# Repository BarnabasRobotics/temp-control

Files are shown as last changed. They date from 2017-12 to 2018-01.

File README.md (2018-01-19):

# temp-control
Arduino-based temperature display and controller -- Created by Ling Leng

Revision History:
12/27/2017
- Added first version "Bare Bones Arduino.zip"
- Replaced "Bare Bones Arduino.zip" with new "TempControl V1.0" files which only includes .brd and .sch files
- Added Mini USB power supply part
- Added external oscillator
- Removed ISP-6 header
- Added reset button
- Added voltage regulator circuit

1/1/2018
- Added OLED
- Added .lbr file

1/2/2018
- Created new TempControl.lbr
- Created parts list
- Went through every parts and replaced them with TempControl.lbr
- Replaced ams1117 with L7805C
- Replaced the reset button
- Removed two LEDs
- Changed packages fot some capacitors
- Added frame

1/3/2018
- For U2, Added 0.33uF on Pin1 and 0.1uF on Pin3
- For U1, Added 0.1uF on Pin7 and 1.0uF on Pin20
- Added Diode on Pin1 for J3, Power Pin for J1, and VCC Pin for J4
- Added Green LED as power indicator
- Added a 4-PIN connector for OLED
- Rearranged and Rerouted the whole board

1/8/2018
- Removed power jack
- Removed 5V regulator
- Added 3v regulator
- Added level shifter

1/19/2018
- Added temp sensor

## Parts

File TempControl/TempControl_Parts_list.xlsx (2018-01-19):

Parts Name | Website | Price | Quantity | Comment | Custom Package
LD1117V33 | https://www.sparkfun.com/products/526 | 1.95 | 1
Micro USB | https://www.digikey.com/products/en?keywords=609-4618-1-ND | 0.46 | 1
ATMega328P | https://www.sparkfun.com/products/9061 | 4.3 | 1
FSM2JART(switch) | https://www.mouser.com/ProductDetail/TE-Connectivity/FSM2JART/ | 0.15 | 1 |  | 1
Logic Level Converter | https://www.sparkfun.com/products/12009 | 2.95 | 1
6-PIN |  |  | 1
8-PIN |  |  | 1
4-PIN |  |  | 1
LED RED DIFF 5MM ROUND T/H | https://www.digikey.com/product-detail/en/lite-on-inc/LTL-4223/160-1127-ND/200395 | 0.36 | 1
LED GREEN | https://www.digikey.com/products/en?keywords=160-1435-1-ND | 0.27 | 1
OLED | https://www.amazon.com/0-91-128x32-OLED-module-White/dp/B01IBCZB0M | 13.5 | 1 |  | 1
Crystal 16MHz | https://www.sparkfun.com/products/536 | 0.95 | 1
Schottky Diode | https://www.digikey.com/products/en?keywords=478-7802-1-ND | 0.54 | 2
Capacitor Ceramic Disc 22pF | http://www.sparkfun.com/products/8571 | 0.25 | 2
Capacitor Ceramic Disc 0.1uF | https://www.sparkfun.com/products/8375 | 0.25 | 3
Ceramic Capacitor 10uF | https://www.digikey.com/product-detail/en/tdk-corporation/FK24X5R1A106K/445-8493-ND/2815423 | 0.45 | 1
Ceramic Capacitor 1.0uF | https://www.digikey.com/product-detail/en/tdk-corporation/FK24X7R1H105K/445-8517-ND/2815447 | 0.4 | 1
Resistor 10K Ohm | https://www.sparkfun.com/products/14491 | 0.95 | 1
Resistor 4.7K Ohm | https://www.digikey.com/product-detail/en/stackpole-electronics-inc/CF14JT4K70/CF14JT4K70TR-ND/1741428 |  | 1
Resistor 1K Ohm | https://www.digikey.com/products/en?keywords=311-1.00KHRCT-ND | 0.1 | 2
Temperature Sensor - DS18B20 | https://www.sparkfun.com/products/245 | 3.95 | 1

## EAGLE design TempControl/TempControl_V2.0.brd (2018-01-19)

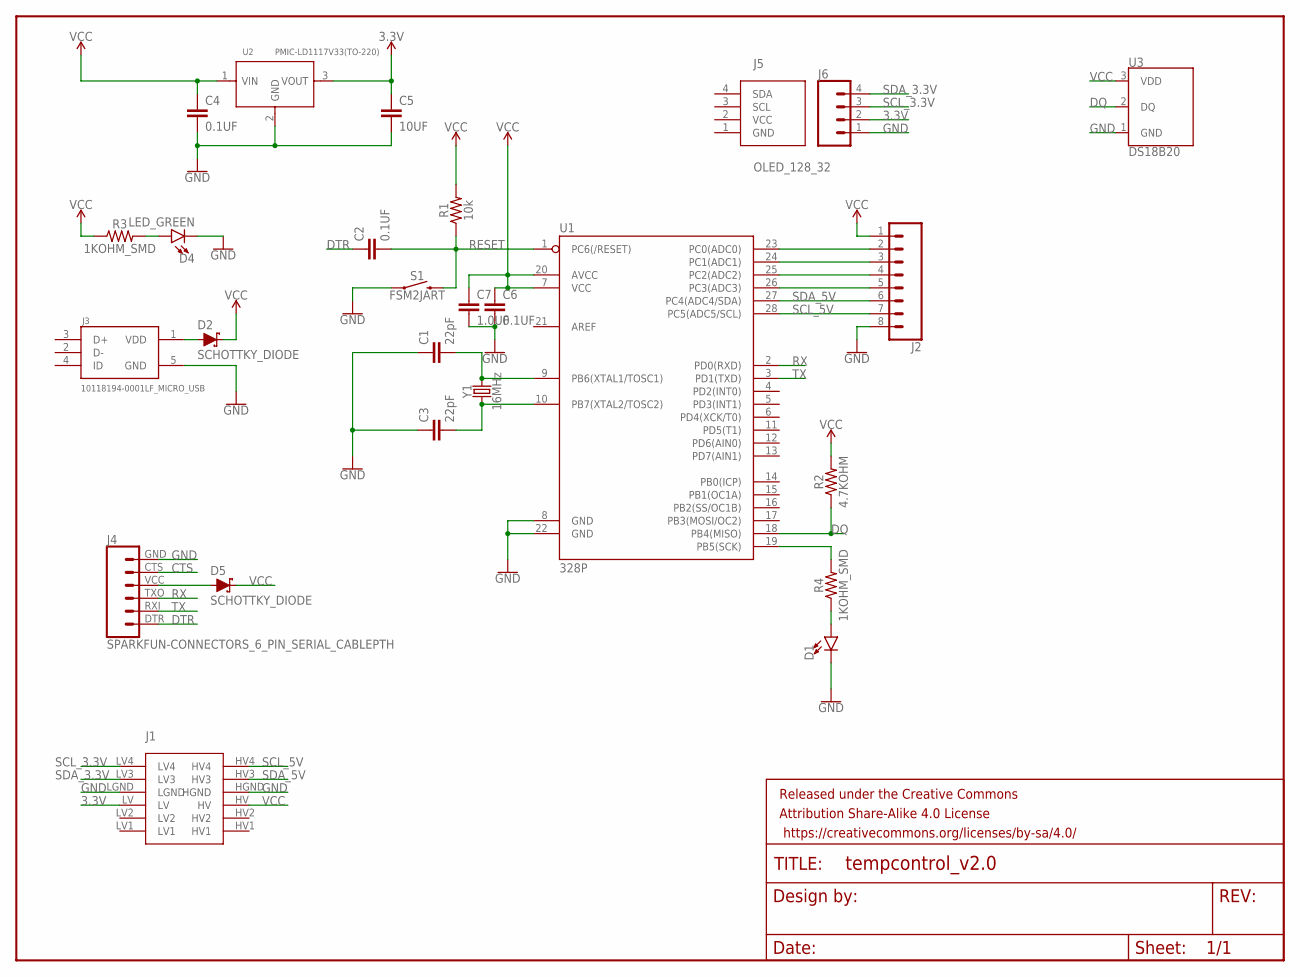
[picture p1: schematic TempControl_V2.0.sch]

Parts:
C1, C3: 22pF; CAP-PTH-2.54
C2, C4, C6: 0.1UF; CAP-PTH-2.54
C5: 10UF; CAP-PTH-5MM
C7: 1.0UF; CAP-PTH-5MM
D1: LED_RED5MM; LED_5MM
D2, D5: SCHOTTKY_DIODE; DIODE_0805
D4: LED_GREEN; LED-0603
FRAME1: FRAME-LETTERNO_PACKAGE; DUMMY
J1: LEVEL_SHIFTER
J2: SPARKFUN-CONNECTORS_CONN_08"; SPARKFUN-CONNECTORS_1X08
J3: 10118194-0001LF_MICRO_USB; FRAMATOME_10118194-0001LF
J4: SPARKFUN-CONNECTORS_6_PIN_SERIAL_CABLEPTH; SPARKFUN-CONNECTORS_FTDI_BASIC
J5: OLED_128_32
J6: CONN_04; 1X04
R1: 10k; AXIAL-0.3
R2: 4.7KOHM; AXIAL-0.3
R3, R4: 1KOHM_SMD; 0603
S1: FSM2JART
U1: 328P; DIP28
U2: PMIC-LD1117V33(TO-220); TO-220
U3: DS18B20; TO-92-AMMO
Y1: 16MHz; HC49US

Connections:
3.3V: C5.1, J1.LV, J6.2, U2.3 (VOUT)
CTS: J4.CTS (5)
DQ: R2.P$1 (1), U1.18 (PB4(MISO)), U3.2 (DQ)
DTR: C2.1, J4.DTR (1)
GND: C1.1, C3.1, C4.2, C5.2, C6.2, C7.2, D1.K (2), D4.2, J1.HGND, J1.LGND, J2.8, J3.5 (GND), J4.GND (6), J6.1, S1.1, U1.8 (GND), U1.22 (GND), U2.2 (GND), U3.1 (GND)
unnamed: J2.2, U1.23 (PC0(ADC0))
unnamed: J2.3, U1.24 (PC1(ADC1))
unnamed: J2.4, U1.25 (PC2(ADC2))
unnamed: J2.5, U1.26 (PC3(ADC3))
unnamed: C1.2, U1.9 (PB6(XTAL1/TOSC1)), Y1.2
unnamed: R4.2, U1.19 (PB5(SCK))
unnamed: D2.1, J3.1 (VDD)
unnamed: D1.A (1), R4.1
unnamed: D4.1, R3.2
unnamed: C3.2, U1.10 (PB7(XTAL2/TOSC2)), Y1.1
unnamed: D5.1, J4.VCC (4)
RESET: C2.2, R1.P$1 (1), S1.2, U1.1 (PC6(/RESET))
RX: J4.TXO (3), U1.2 (PD0(RXD))
SCL_3.3V: J1.LV4, J6.3
SCL_5V: J1.HV4, J2.7, U1.28 (PC5(ADC5/SCL))
SDA_3.3V: J1.LV3, J6.4
SDA_5V: J1.HV3, J2.6, U1.27 (PC4(ADC4/SDA))
TX: J4.RXI (2), U1.3 (PD1(TXD))
VCC: C4.1, C6.1, C7.1, D2.2, D5.2, J1.HV, J2.1, R1.P$2 (2), R2.P$2 (2), R3.1, U1.7 (VCC), U1.20 (AVCC), U2.1 (VIN), U3.3 (VDD)

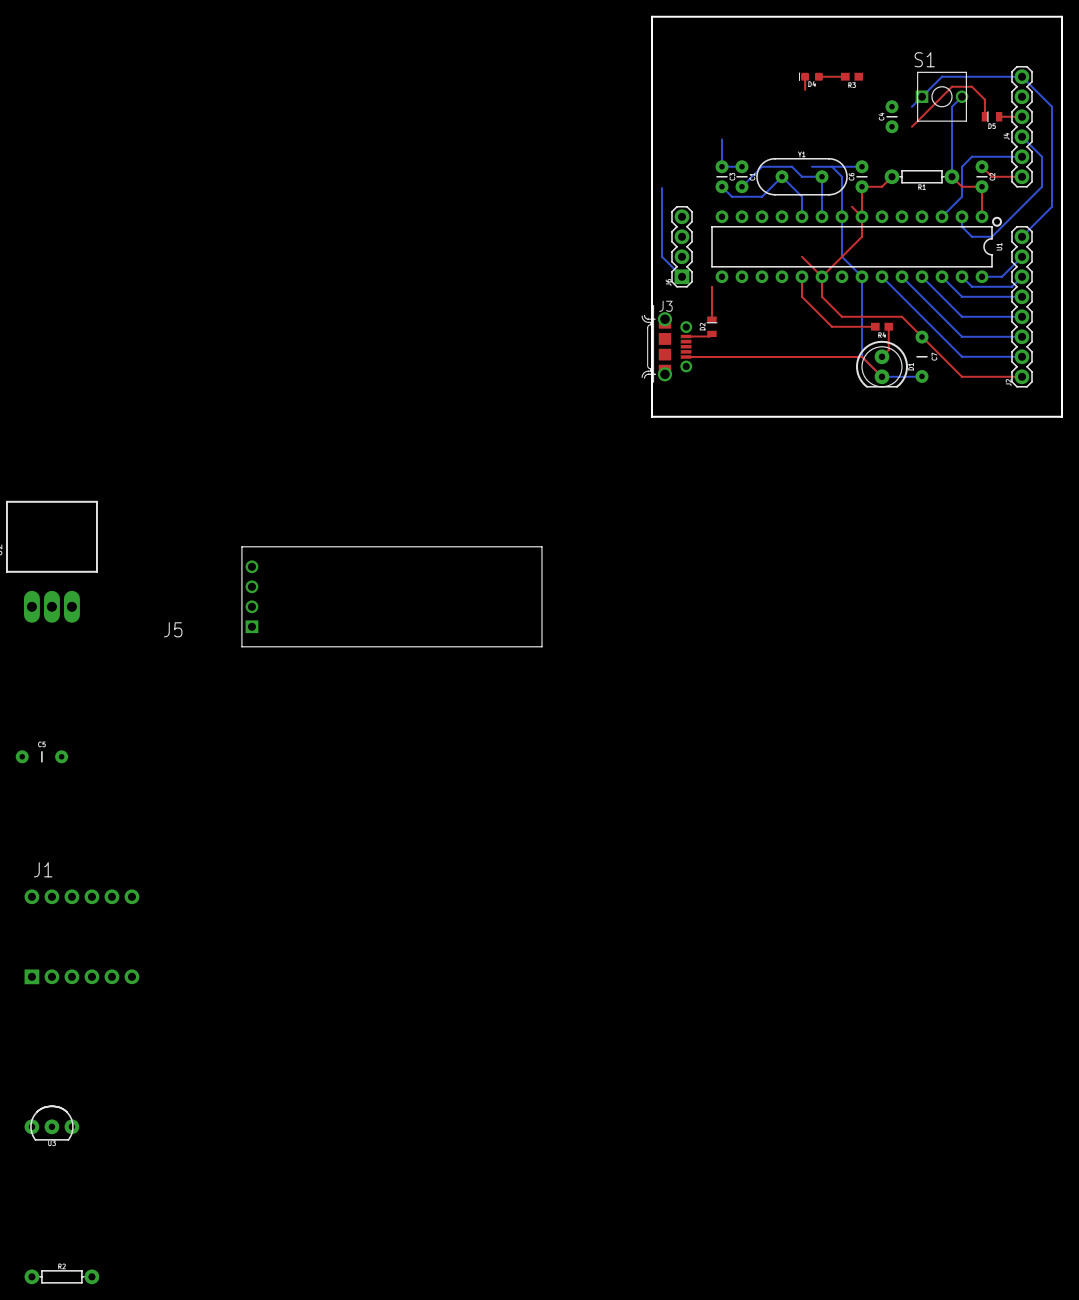
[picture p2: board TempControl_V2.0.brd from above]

Board: 2 copper layers, 52.1 x 50.8 mm, 27 parts (0 on the bottom side), 23 nets.

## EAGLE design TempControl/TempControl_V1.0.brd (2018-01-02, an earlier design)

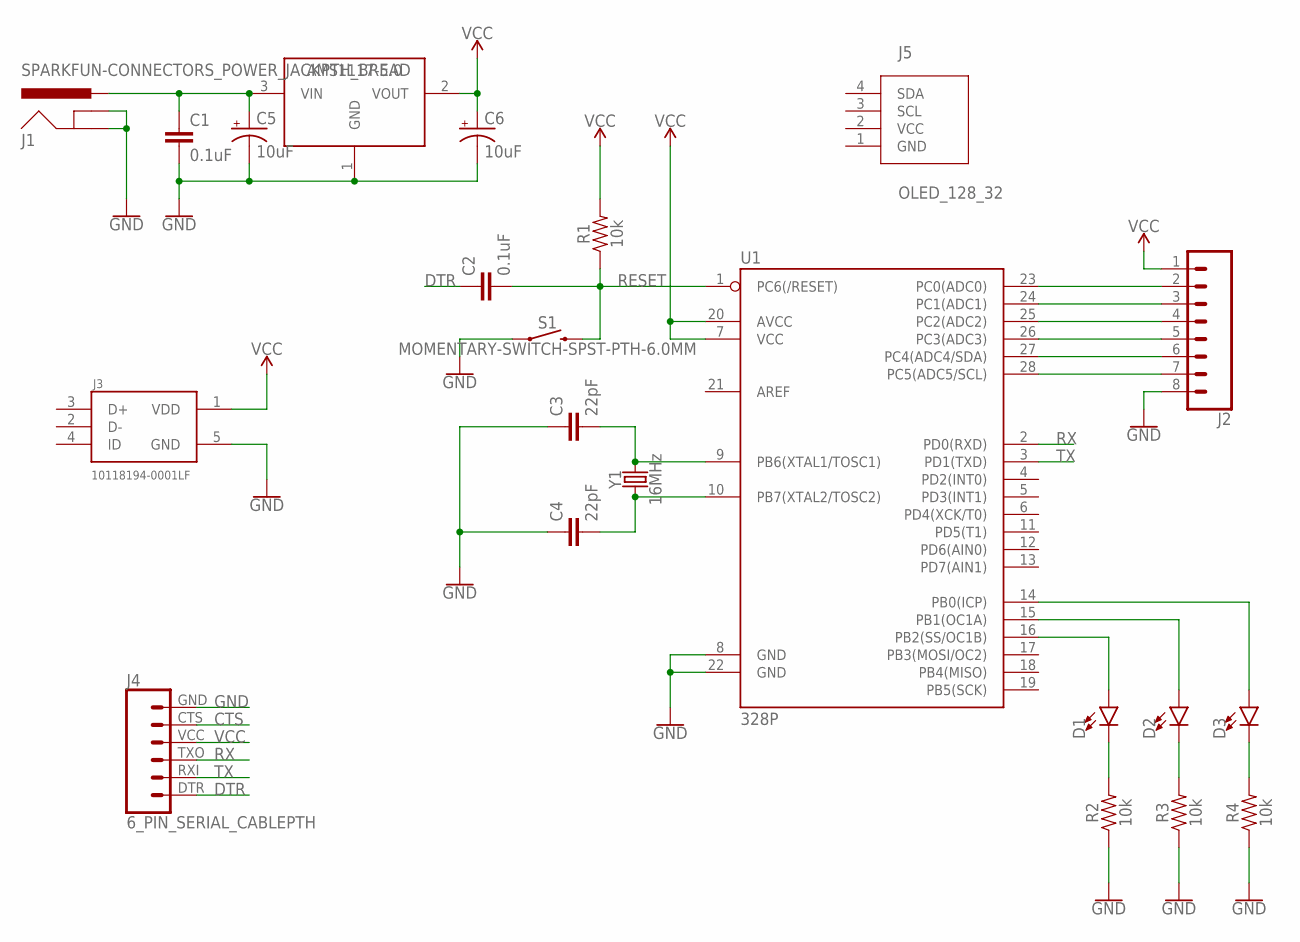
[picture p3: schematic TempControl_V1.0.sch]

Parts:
C1, C2: 0.1uF; CAP-PTH-SMALL-KIT
C3, C4: 22pF; CAP-PTH-2.54
C5, C6: 10uF; CPOL-RADIAL-2.5MM-5MM
D1, D2, D3: LED5MM; LED_5MM
J1: SPARKFUN-CONNECTORS_POWER_JACKPTH_BREAD; SPARKFUN-CONNECTORS_POWER_JACK_PTH_BREAD
J2: CONN_08"; 1X08
J3: 10118194-0001LF; FRAMATOME_10118194-0001LF
J4: 6_PIN_SERIAL_CABLEPTH; FTDI_BASIC
J5: OLED_128_32
R1, R2, R3, R4: 10k; AXIAL-0.3
S1: MOMENTARY-SWITCH-SPST-PTH-6.0MM; TACTILE_SWITCH_PTH_6.0MM
U1: 328P; DIP28
U$1: AMS1117-5.0; SOT223
Y1: 16MHz; HC49US

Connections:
CTS: J4.CTS (5)
DTR: C2.1, J4.DTR (1)
GND: C1.2, C3.1, C4.1, C5.2 (-), C6.2 (-), J1.GND, J1.GNDBREAK, J2.8, J3.5 (GND), J4.GND (6), R2.P$1 (1), R3.P$1 (1), R4.P$1 (1), S1.1, U1.8 (GND), U1.22 (GND), U$1.1 (GND)
unnamed: J2.2, U1.23 (PC0(ADC0))
unnamed: J2.3, U1.24 (PC1(ADC1))
unnamed: J2.4, U1.25 (PC2(ADC2))
unnamed: J2.5, U1.26 (PC3(ADC3))
unnamed: J2.6, U1.27 (PC4(ADC4/SDA))
unnamed: J2.7, U1.28 (PC5(ADC5/SCL))
unnamed: C3.2, U1.9 (PB6(XTAL1/TOSC1)), Y1.2
unnamed: D3.A, U1.14 (PB0(ICP))
unnamed: D2.A, U1.15 (PB1(OC1A))
unnamed: D1.A, U1.16 (PB2(SS/OC1B))
unnamed: D3.K (C), R4.P$2 (2)
unnamed: D2.K (C), R3.P$2 (2)
unnamed: D1.K (C), R2.P$2 (2)
unnamed: C4.2, U1.10 (PB7(XTAL2/TOSC2)), Y1.1
unnamed: C1.1, C5.1 (+), J1.PWR, U$1.3 (VIN)
RESET: C2.2, R1.P$1 (1), S1.3 (2), U1.1 (PC6(/RESET))
RX: J4.TXO (3), U1.2 (PD0(RXD))
TX: J4.RXI (2), U1.3 (PD1(TXD))
VCC: C6.1 (+), J2.1, J3.1 (VDD), J4.VCC (4), R1.P$2 (2), U1.7 (VCC), U1.20 (AVCC), U$1.2 (VOUT)

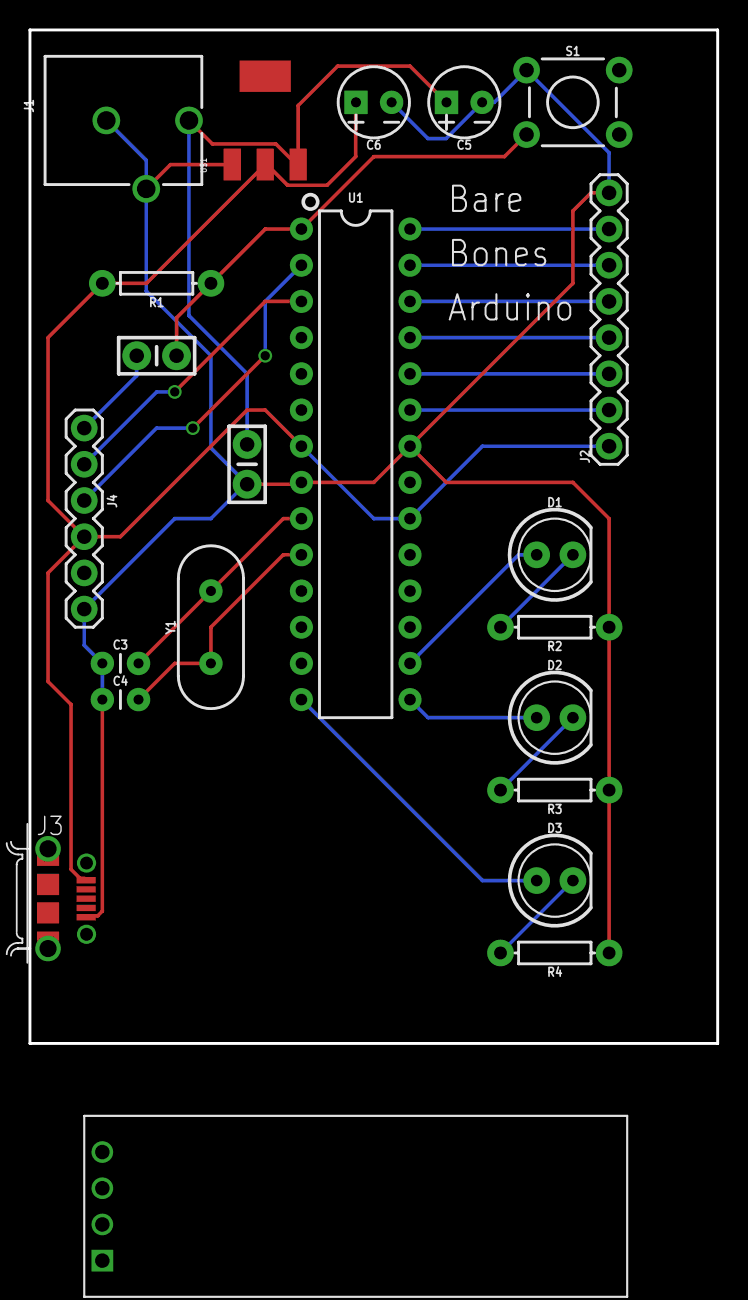
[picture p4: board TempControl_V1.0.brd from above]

Board: 2 copper layers, 48.3 x 71.1 mm, 22 parts (0 on the bottom side), 21 nets.

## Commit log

2017-12-27 Eagle Files
    Include Schematic and PCB Layout
2017-12-28 Delete Bare Bones Arduino.zip
    Replace it with new TempControl files
2017-12-28 Update new eagle files
    .brd and .sch for TempControl V1.0
    [TempControl.brd, TempControl.sch]
2018-01-02 - Added .lbr file for TempControl project - Added OLED part - Rename the project name
    [TempControl.brd, TempControl.sch]
2018-01-03 A lot of changes happened
    - Added new TempControl.lbr
    - Added parts list
    - Modified and added many parts
    - Redesigned the board
    [TempControl_Parts_list.xlsx, TempControl_V1.0.brd, TempControl_V1.0.sch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]
2018-01-19 - updated schematic and layout
    - removed power jack
    - added 3.3V regulator
    - added OLED
    - added level shifter
    - added temp sensor
    [TempControl_Parts_list.xlsx, TempControl_V1.0.brd, TempControl_V1.0.sch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]

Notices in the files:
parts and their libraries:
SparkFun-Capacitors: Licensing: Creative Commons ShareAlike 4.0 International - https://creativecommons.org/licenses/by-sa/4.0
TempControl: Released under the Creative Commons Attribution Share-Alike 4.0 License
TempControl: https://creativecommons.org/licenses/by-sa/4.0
